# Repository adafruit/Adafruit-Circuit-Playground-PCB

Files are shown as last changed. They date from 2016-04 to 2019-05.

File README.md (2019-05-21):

## Adafruit Circuit Playground Classic PCB
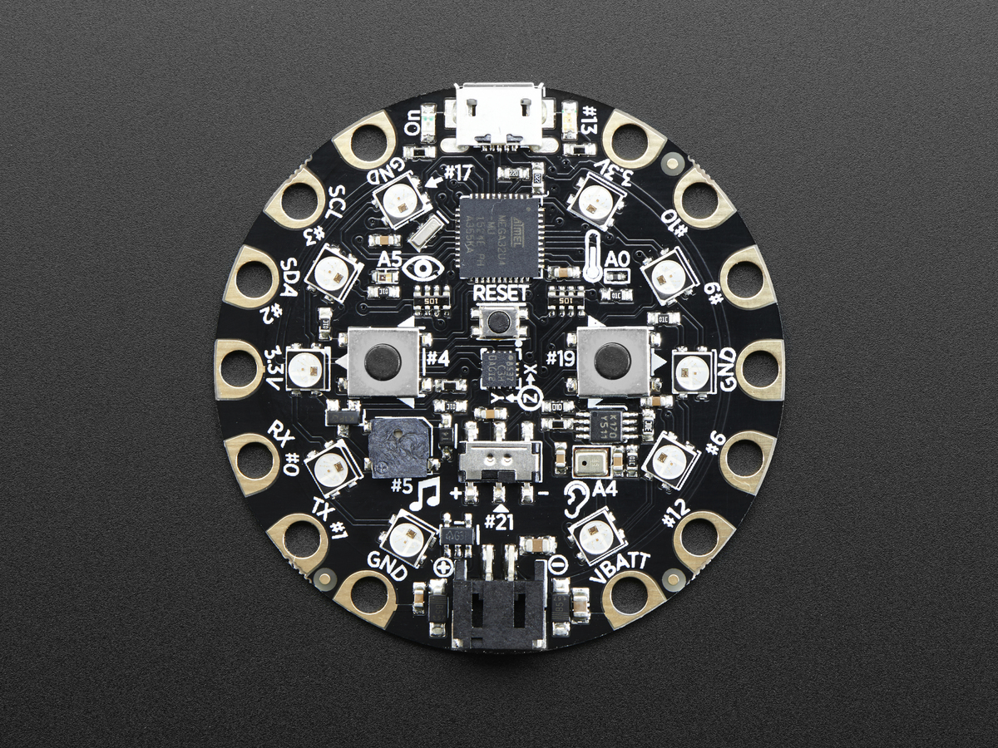
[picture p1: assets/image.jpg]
<a href="http://www.adafruit.com/products/3000"><br/>
Click here to purchase one from the Adafruit shop</a>

This is the Classic version of Circuit Playground, which comes with an ATmega32u4. It's designed to be used with Arduino IDE and code.org CS Discoveries only. It even comes with Firmata already programmed in, so you can use it immediately with code.org Discoveries without any preparation or updates.

If you would like to use MakeCode or CircuitPython, check out [Circuit Playground Express](http://www.adafruit.com/products/3333), which can be used with MakeCode, CircuitPython or Arduino.

Circuit Playground features an ATmega32u4 processor, just like our popular Flora. The board's also round and has alligator-clip pads around it so you don't have to solder or sew to make it work. You can power it from USB, a AAA battery pack, or with a Lipoly battery (for advanced users). Just program your code into the board then take it on the go!

This is the PCB files for the Adafruit **Circuit Playground Classic** (not the Express). The format is EagleCAD schematic and board layout
- http://www.adafruit.com/products/3000

**The Circuit Playground Express can be found at http://www.adafruit.com/products/3333**

### License

Adafruit invests time and resources providing this open source design, please support Adafruit and open-source hardware by purchasing products from [Adafruit](https://www.adafruit.com)!

All text above must be included in any redistribution

Designed by Limor Fried/Ladyada for Adafruit Industries.
Creative Commons Attribution/Share-Alike, all text above must be included in any redistribution. 
See license.txt for additional information.

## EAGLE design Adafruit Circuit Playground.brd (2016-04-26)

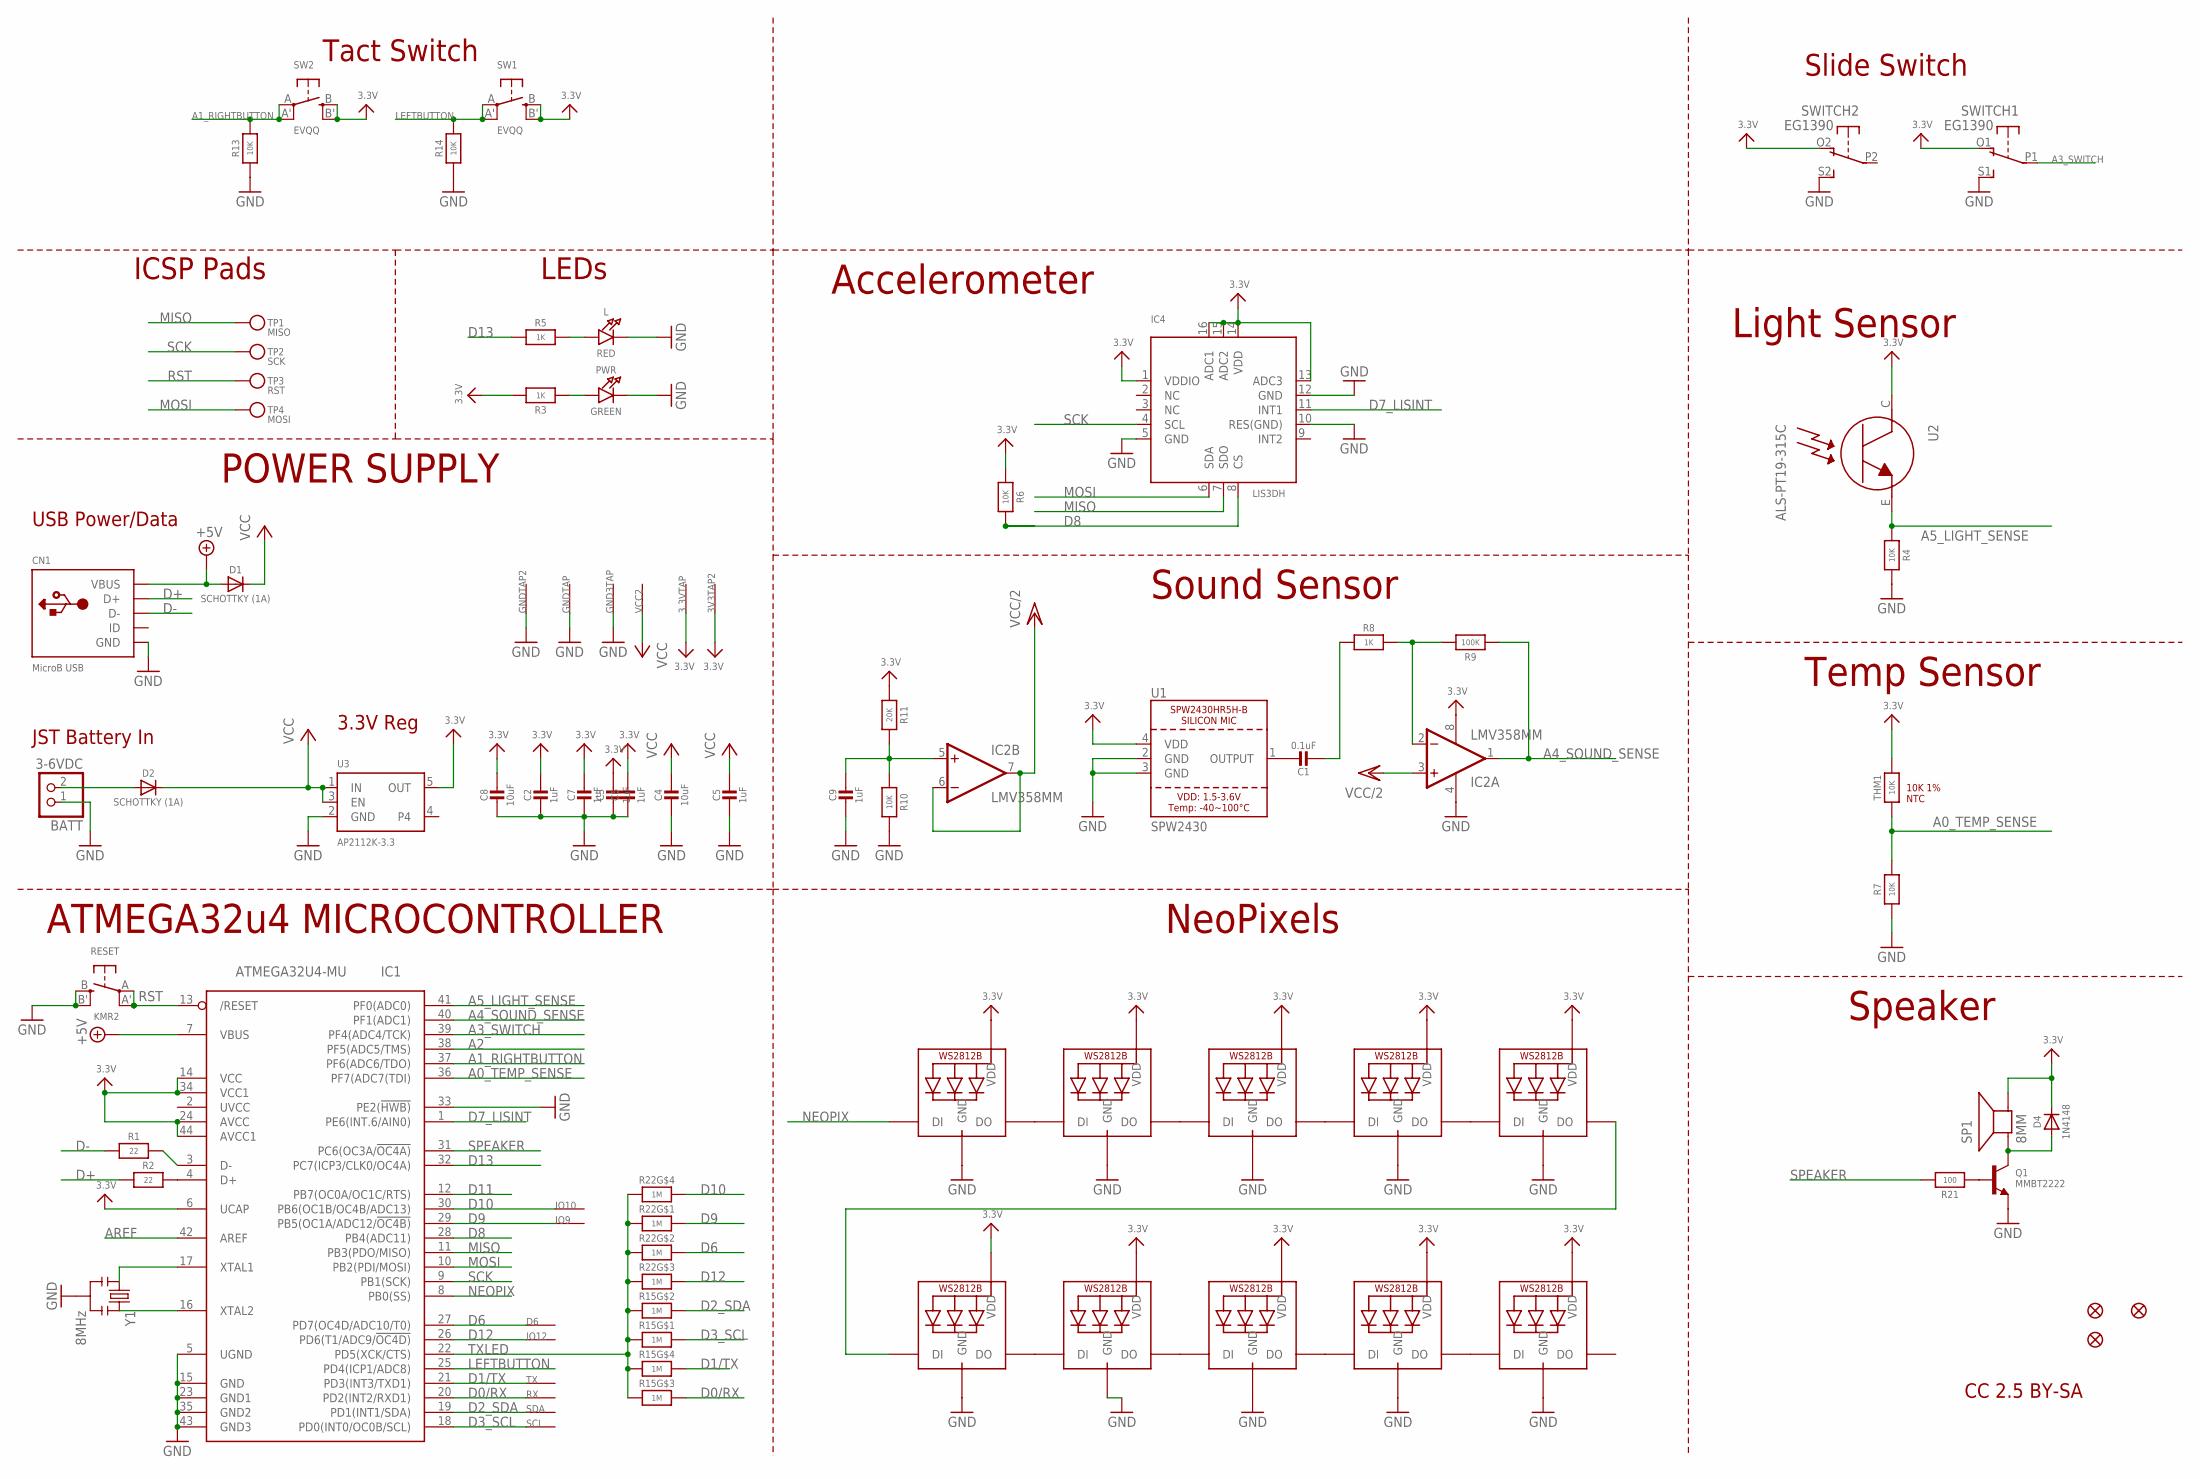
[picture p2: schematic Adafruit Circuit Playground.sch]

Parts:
3.3VTAP, 3V3TAP2: SEWTAP-ALLIGATOR; SEWALLI
BATT: 3-6VDC; JSTPH2
C1: 0.1uF; 0603-NO
C2, C3, C5, C6, C7, C9: 1uF; 0603-NO
C4, C8: 10uF; 0805-NO
CN1: MicroB USB; 4UCONN_20329_V2
D1, D2: SCHOTTKY (1A); SOD-123
D4: 1N4148; SOD-323
D6: SEWTAP-ALLIGATOR; SEWALLI
GND3TAP: SEWTAP-ALLIGATOR; SEWALLI
GNDTAP, GNDTAP2: SEWTAP-ALLIGATOR; SEWALLI
IC1: ATMEGA32U4-MU; TQFN44_7MM
IC2: LMV358MM; MSOP08
IC4: LIS3DH; LGA16_3X3MM
IO9, IO10, IO12: SEWTAP-ALLIGATOR; SEWALLI
L: RED; CHIPLED_0805_NOOUTLINE
LED1, LED2, LED3, LED4, LED5, LED6, LED7, LED8, LED9, LED10: WS2812B3535; LED3535
PWR: GREEN; CHIPLED_0805_NOOUTLINE
Q1: MMBT2222; SOT23-WIDE
R1, R2: 22; 0603-NO
R3, R5, R8: 1K; 0603-NO
R4, R6, R7, R10, R13, R14: 10K; 0603-NO
R9: 100K; 0603-NO
R11: 20K; 0603-NO
R15, R22: 1M; RESPACK_4X0603_NO
R21: 100; 0603-NO
RESET: KMR2; BTN_KMR2_4.6X2.8
RX: SEWTAP-ALLIGATOR; SEWALLI
SCL: SEWTAP-ALLIGATOR; SEWALLI
SDA: SEWTAP-ALLIGATOR; SEWALLI
SP1: 8MM; BUZZER_SMT_5MM
SW1, SW2: EVQQ; EVQ-Q2_SMALLER
SWITCH: EG1390
THM1: 10K; _0402
TP1: MISO; TESTPOINT_ROUND_1.5MM
TP2: SCK; TESTPOINT_ROUND_1.5MM
TP3: RST; TESTPOINT_ROUND_1.5MM
TP4: MOSI; TESTPOINT_ROUND_1.5MM
TX: SEWTAP-ALLIGATOR; SEWALLI
U1: SPW2430; SPW2430HR5H-B
U2: ALS-PT19-315C
U3: AP2112K-3.3; SOT23-5
U$2, U$3, U$6: FIDUCIAL""; FIDUCIAL_1MM
VCC2: SEWTAP-ALLIGATOR; SEWALLI
Y1: 8MHz; RESONATOR-SMD

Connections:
3.3V: 3.3VTAP.P$1, 3V3TAP2.P$1, C2.1, C3.1, C6.1, C7.1, C8.1, D4.C, IC1.6 (UCAP), IC1.14 (VCC), IC1.24 (AVCC), IC1.34 (VCC1), IC1.44 (AVCC1), IC2.8 (V+), IC4.1 (VDDIO), IC4.13 (ADC3), IC4.14 (VDD), IC4.15 (ADC2), IC4.16 (ADC1), LED1.2 (VDD), LED2.2 (VDD), LED3.2 (VDD), LED4.2 (VDD), LED5.2 (VDD), LED6.2 (VDD), LED7.2 (VDD), LED8.2 (VDD), LED9.2 (VDD), LED10.2 (VDD), R3.2, R6.1, R11.1, SP1.-, SW1.B (S), SW1.B' (S1), SW2.B (S), SW2.B' (S1), SWITCH.O1 (O), SWITCH.O2 (O), THM1.2, U1.4 (VDD), U2.C, U3.5 (OUT)
+5V: CN1.VBUS, D1.A, IC1.7 (VBUS)
A0_TEMP_SENSE: IC1.36 (PF7(ADC7(TDI)), R7.2, THM1.1
A1_RIGHTBUTTON: IC1.37 (PF6(ADC6/TDO)), R13.2, SW2.A, SW2.A' (P1)
A2: IC1.38 (PF5(ADC5/TMS))
A3_SWITCH: IC1.39 (PF4(ADC4/TCK)), SWITCH.P1
A4_SOUND_SENSE: IC1.40 (PF1(ADC1)), IC2.1 (OUT), R9.1
A5_LIGHT_SENSE: IC1.41 (PF0(ADC0)), R4.2, U2.E
AREF: IC1.42 (AREF)
D0/RX: IC1.20 (PD2(INT2/RXD1)), R15.6 (2), RX.P$1
D1/TX: IC1.21 (PD3(INT3/TXD1)), R15.5 (2), TX.P$1
D2_SDA: IC1.19 (PD1(INT1/SDA)), R15.7 (2), SDA.P$1
D3_SCL: IC1.18 (PD0(INT0/OC0B/SCL)), R15.8 (2), SCL.P$1
D6: D6.P$1, IC1.27 (PD7(OC4D/ADC10/T0)), R22.7 (2)
D7_LISINT: IC1.1 (PE6(INT.6/AIN0)), IC4.11 (INT1)
D8: IC1.28 (PB4(ADC11)), IC4.8 (CS), R6.2
D9: IC1.29 (PB5(OC1A/ADC12/!OC4B)), IO9.P$1, R22.8 (2)
D10: IC1.30 (PB6(OC1B/OC4B/ADC13)), IO10.P$1, R22.5 (2)
D11: IC1.12 (PB7(OC0A/OC1C/RTS))
D12: IC1.26 (PD6(T1/ADC9/!OC4D)), IO12.P$1, R22.6 (2)
D13: IC1.32 (PC7(ICP3/CLK0/OC4A)), R5.1
D+: CN1.D+, R2.1
D-: CN1.D-, R1.1
GND: BATT.1, C2.2, C3.2, C4.2, C5.2, C6.2, C7.2, C8.2, C9.2, CN1.BASE@1 (GND), CN1.BASE@2 (GND), CN1.GND, CN1.SPRT@1 (GND), CN1.SPRT@2 (GND), CN1.SPRT@3 (GND), CN1.SPRT@4 (GND), GND3TAP.P$1, GNDTAP.P$1, GNDTAP2.P$1, IC1.5 (UGND), IC1.15 (GND), IC1.23 (GND1), IC1.33 (PE2(!HWB)), IC1.35 (GND2), IC1.43 (GND3), IC2.4 (V-), IC4.5 (GND), IC4.10 (RES(GND)), IC4.12 (GND), L.C, LED1.4 (GND), LED2.4 (GND), LED3.4 (GND), LED4.4 (GND), LED5.4 (GND), LED6.4 (GND), LED7.4 (GND), LED8.4 (GND), LED9.4 (GND), LED10.4 (GND), PWR.C, Q1.2 (E), R4.1, R7.1, R10.2, R13.1, R14.1, RESET.B (S), RESET.B' (S1), SWITCH.S1 (S), SWITCH.S2 (S), U1.2 (GND), U1.3 (GND), U3.2 (GND), Y1.2
LEFTBUTTON: IC1.25 (PD4(ICP1/ADC8)), R14.2, SW1.A, SW1.A' (P1)
MISO: IC1.11 (PB3(PDO/MISO)), IC4.7 (SDO), TP1.P$1
MOSI: IC1.10 (PB2(PDI/MOSI)), IC4.6 (SDA), TP4.P$1
unnamed: PWR.A, R3.1
unnamed: IC2.2 (-IN), R8.2, R9.2
unnamed: IC1.3 (D-), R1.2
unnamed: IC1.4 (D+), R2.2
unnamed: C9.1, IC2.5 (+IN), R10.1, R11.2
unnamed: BATT.2, D2.A
unnamed: IC1.17 (XTAL1), Y1.1
unnamed: IC1.16 (XTAL2), Y1.3
unnamed: L.A, R5.2
unnamed: LED1.1 (DI), LED2.3 (DO)
unnamed: LED1.3 (DO), LED3.1 (DI)
unnamed: LED2.1 (DI), LED10.3 (DO)
unnamed: LED6.3 (DO), LED7.1 (DI)
unnamed: C1.2, R8.1
unnamed: LED7.3 (DO), LED8.1 (DI)
unnamed: LED8.3 (DO), LED9.1 (DI)
unnamed: LED9.3 (DO), LED10.1 (DI)
unnamed: LED3.3 (DO), LED4.1 (DI)
unnamed: LED4.3 (DO), LED5.1 (DI)
unnamed: D4.A, Q1.3 (C), SP1.+
unnamed: Q1.1 (B), R21.1
NEOPIX: IC1.8 (PB0(SS)), LED6.1 (DI)
RST: IC1.13 (/RESET), RESET.A, RESET.A' (P1), TP3.P$1
SCK: IC1.9 (PB1(SCK)), IC4.4 (SCL), TP2.P$1
SOUNDOUT: C1.1, U1.1 (OUTPUT)
SPEAKER: IC1.31 (PC6(OC3A/!OC4A)), R21.2
TXLED: IC1.22 (PD5(XCK/CTS)), R15.1, R15.2 (1), R15.3 (1), R15.4 (1), R22.1, R22.2 (1), R22.3 (1), R22.4 (1)
VCC: C4.1, C5.1, D1.C, D2.C, U3.1 (IN), U3.3 (EN), VCC2.P$1
VCC/2: IC2.3 (+IN), IC2.6 (-IN), IC2.7 (OUT)

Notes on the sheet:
CC 2.5 BY-SA
10K 1% NTC
ATMEGA32u4 MICROCONTROLLER
USB Power/Data
JST Battery In
3.3V Reg
POWER SUPPLY
NeoPixels
Speaker
Temp Sensor
Light Sensor
Sound Sensor
Slide Switch
Tact Switch
LEDs
ICSP Pads
Accelerometer

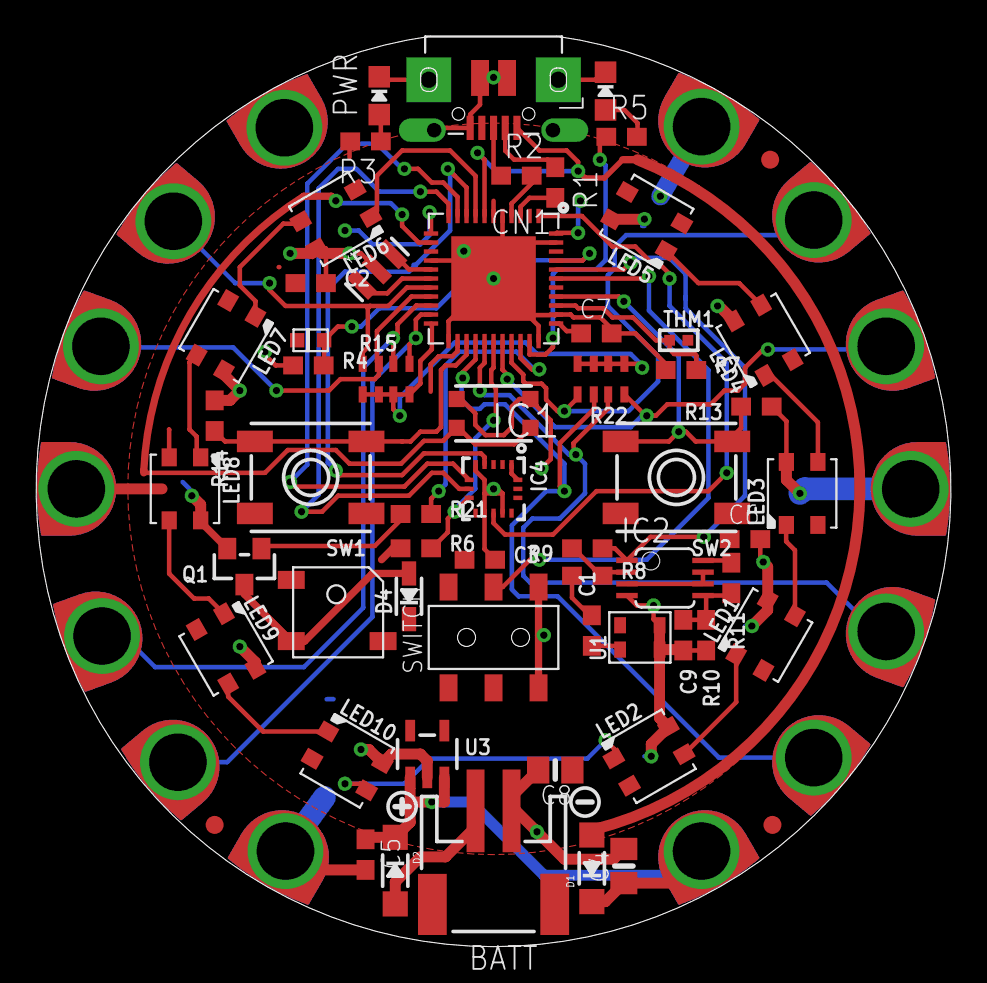
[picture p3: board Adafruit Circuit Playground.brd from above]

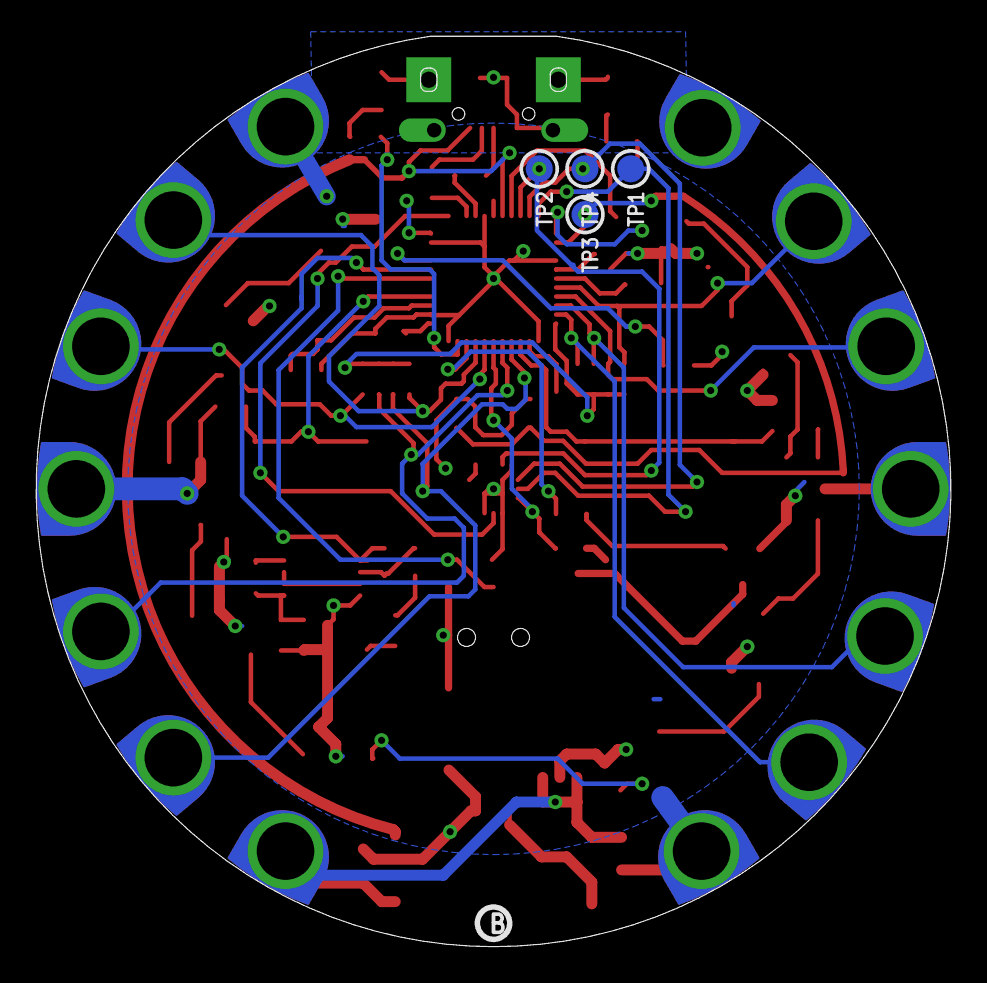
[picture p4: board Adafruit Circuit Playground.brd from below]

Board: 2 copper layers, 50.8 x 50.6 mm, 83 parts (7 on the bottom side), 53 nets.

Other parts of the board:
U$1: SYMBOL_MINUS
U$4: FLORAMED
U$7: PCBFEAT-REV-040
U$34: CPLAYFRONT
U$35: SYMBOL_PLUS
U$46: CPLAYBACK

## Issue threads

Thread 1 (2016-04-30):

eagle does not open

billball61, 2016-04-30:
The board file fails to open in Eagle with this message:
line 6, column 73: This is not an EAGLE file.

microbuilder, 2016-04-30:
You likely have an old version of Eagle that doesn't support XML files.  Please use a more recent version. This board is designed in Eagle 6.4.

billball61, 2016-04-30:
My problem is not the version but maybe because I was using the light edition (ver 7.5) to open a larger board than it will support? Just trying to get the dimensions of the board & components to start on a case design.

billball61, 2016-05-01:
Oops, it was still in zip. Never mind :)

Closed 2016-04-30.

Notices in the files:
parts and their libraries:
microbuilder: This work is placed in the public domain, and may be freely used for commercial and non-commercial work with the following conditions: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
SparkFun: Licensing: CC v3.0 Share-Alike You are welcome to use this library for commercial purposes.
